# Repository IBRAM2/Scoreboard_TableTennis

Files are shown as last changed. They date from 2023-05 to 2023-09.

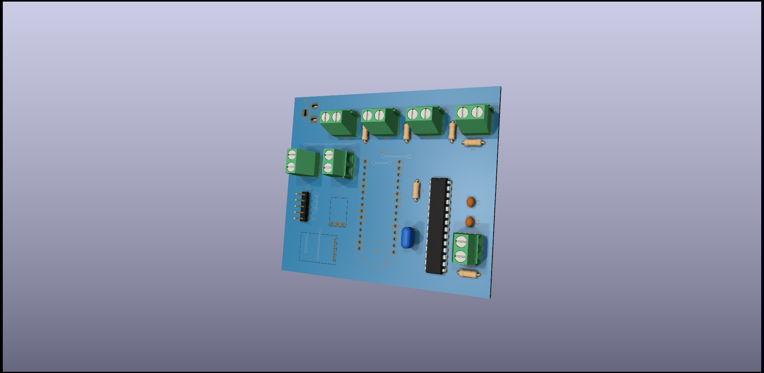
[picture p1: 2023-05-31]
Kicad/MarcadorPing2/MarcadorPing2.png

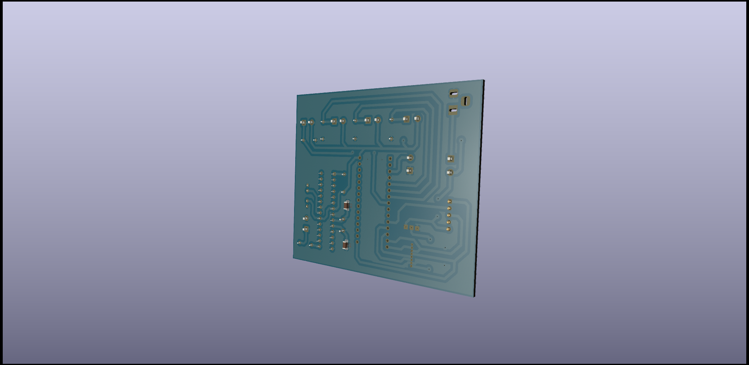
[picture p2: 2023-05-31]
Kicad/MarcadorPing2/MarcadorPing2_2.png

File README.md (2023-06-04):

# Tennis Scoreboard

## Simulation
The software used to perform the circuit simulations is proteus, this software its not free, so I provide a "student" version below.

Download Link: [Proteus Student Version](https://drive.google.com/drive/folders/1Nruetk5m6KCmWx57GLWE98xntiZ9FSeq?usp=drive_link)

### Installation Instructions

You need Windows OS to install proteus
1. Install the .exe, the default ***installation_path*** is: 
    > C:\Program Files (x86)\Labcenter Electronics\Proteus 8 Professional

2. On ***installation_path***/DATA/LIBRARY paste the contents of **"librerias-arduino"**

3. (Optional) On ***installation_path*** remplace Translations directory with the content of **"Paquete de idiomas"**.

### Run Simulation
1. Open **Arduino IDE**, go to File, preferences, and select verbose on compilation.

2. Compile the program, Towards the end of the terminal output, you will be able to see the path where the program was compiled
    > C:\\Users\\name\\AppData\\Local\\Temp\\arduino-sketch-38788937E004AF96E05C05CDE8CDFB3A\Scoreboard.ino.elf
    >
    Copy the path from the terminal or locate the indicated path, remember that the separators are \ and remove the " at the beginning and end.

3. Open the simulation, and double click on arduino nano, paste the path of the file .elf or .hex on **Program File:**

4. Run the simulatior by clicking on the play symbol in the bottom left corner.

*Note: Due to Arduino compiling the program into temporary files, it's possible that program execution may modify the path. However, this usually doesn't happen within the same session unless you restart the computer.*

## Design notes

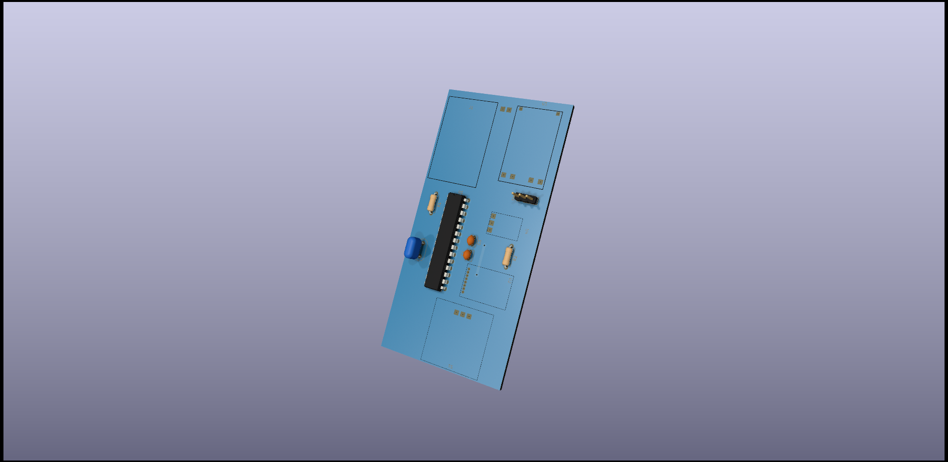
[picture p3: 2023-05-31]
Kicad/MarcadorPing/MarcadorPing.png

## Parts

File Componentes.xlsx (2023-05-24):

Opción 1
Componente | Cantidad | Precio Unitario | Subtotal
MAX7219 Letrero Electrónico Matriz 8x8 (https://uelectronics.com/producto/letrero-electronico-matriz-modulo-8x8-max7219/) | 2 | $122.00 | $244.00
Matriz 8x8 Max7219 Led (https://uelectronics.com/producto/matriz-8x8-max7219-led/) | 2 | $41.00 | $82.00
Interruptor ON OFF Negro 2 Pines 125V 6A (https://uelectronics.com/producto/interruptor-on-off-negro-2-pines-127v-10a/) | 1 | $6.00 | $6.00
Interruptor ON OFF Rojo 2 Pines 125V 6A (https://uelectronics.com/producto/interruptor-on-off-rojo-2-pines-125v-6a/) | 1 | $6.00 | $6.00
PBS-11B Interruptores Push Button Diferentes Colores - Rojo (https://uelectronics.com/producto/pbs-11b-interruptores-push-button-diferentes-colores/?attribute_color=Rojo) | 1 | $11.00 | $11.00
PBS-11B Interruptores Push Button Diferentes Colores - Negro (https://uelectronics.com/producto/pbs-11b-interruptores-push-button-diferentes-colores/?attribute_color=Negro) | 1 | $10.00 | $10.00
PBS-11B Interruptores Push Button Diferentes Colores - Verde (https://uelectronics.com/producto/pbs-11b-interruptores-push-button-diferentes-colores/?attribute_color=Verde) | 1 | $11.00 | $11.00
UNO R3 Con Cable ATMEGA328P / SMD CH340G Compatibles con Arduino - UNO R3 SMD CH340G (https://uelectronics.com/producto/arduino-uno-r3-smd/?attribute_placa=UNO+R3+SMD+CH340G) | 1 | $94.00 | $94.00
 |  | Total | $464.00
Pro Mini 5V 16MHz / 3.3 V 8MHz Compatible con Arduino - 3.3V a 8MHz (https://uelectronics.com/producto/pro-mini-5v-3v3-compatible-con-arduino/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) | 2 | $125.00 | $250.00
Boton Tactil sensor capacitivo TTP223B (https://uelectronics.com/producto/boton-tactil-capacitivo-ttp223b/) | 2 | $14.00 | $28.00
Batería LiPo 3.7V 250mAh 502030 (https://uelectronics.com/producto/bateria-lipo-3-7v-250mah-502030/) | 2 | $39.00 | $78.00
TP4056 con Protección Dual MicroUSB / Tipo C Cargador de Baterías Li-Ion Li-Po - Tipo C (https://uelectronics.com/producto/tp4056-con-proteccion-dual-microusb-tipo-c-cargador-de-baterias-li-ion-li-po/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) | 2 | $15.00 | $30.00
Regulador AMS1117 5V a 3.3V (https://uelectronics.com/producto/regulador-ams1117-5v-a-3-3v/) | 2 | $11.00 | $22.00
NRF24L01 Transreceptor SMD con Antena 2.4Ghz (https://uelectronics.com/producto/nrf24l01-transreceptor-smd-con-antena-2-4ghz/) | 3 | $31.00 | $93.00
Interruptor 1 Polo 2 Tiros 3p 2.54mm Pitch (https://uelectronics.com/producto/interruptor-1-polo-2-tiros-3p-2-54mm-pitch/) | 4 | $2.00 | $8.00
 |  | Total | $509.00
 |  | Total Final | $973.00
Opción 2
Componente | Cantidad | Precio Unitario | Subtotal
MAX7219 Letrero Electrónico Matriz 8x8 (https://uelectronics.com/producto/letrero-electronico-matriz-modulo-8x8-max7219/) | 2 | $122.00 | $244.00
Matriz 8x8 Max7219 Led (https://uelectronics.com/producto/matriz-8x8-max7219-led/) | 2 | $41.00 | $82.00
Interruptor ON OFF Negro 2 Pines 125V 6A (https://uelectronics.com/producto/interruptor-on-off-negro-2-pines-127v-10a/) | 1 | $6.00 | $6.00
Interruptor ON OFF Rojo 2 Pines 125V 6A (https://uelectronics.com/producto/interruptor-on-off-rojo-2-pines-125v-6a/) | 1 | $6.00 | $6.00
PBS-11B Interruptores Push Button Diferentes Colores - Rojo (https://uelectronics.com/producto/pbs-11b-interruptores-push-button-diferentes-colores/?attribute_color=Rojo) | 1 | $11.00 | $11.00
PBS-11B Interruptores Push Button Diferentes Colores - Negro (https://uelectronics.com/producto/pbs-11b-interruptores-push-button-diferentes-colores/?attribute_color=Negro) | 1 | $10.00 | $10.00
PBS-11B Interruptores Push Button Diferentes Colores - Verde (https://uelectronics.com/producto/pbs-11b-interruptores-push-button-diferentes-colores/?attribute_color=Verde) | 1 | $11.00 | $11.00
Nano Tipo C / Micro USB Compatible con Arduino - Tipo C (https://uelectronics.com/producto/arduino-uno-r3-smd/?attribute_placa=UNO+R3+SMD+CH340G) | 1 | $118.00 | $118.00
Header Macho Tira de 40 Pines 2.54mm (https://uelectronics.com/producto/header-macho-tira-de-40-pines-2-54mm/) | 2 | $4.00 | $8.00
Cables Dupont Largos 20cm HH MH MM - Hembra-Hembra (https://uelectronics.com/producto/cables-dupont-largos-20cm-hh-mh-mm/?attribute_pa_terminal=hembra-hembra) | 1 | $22.00 | $22.00
 |  | Total | $518.00
Oscilador Cristal Cuarzo HC-49S - 8 Mhz (https://uelectronics.com/producto/oscilador-cristal-cuarzo-hc-49s/?attribute_pa_cristal-cuarzo=8-mhz) | 2 | $4.00 | $8.00
Boton Tactil sensor capacitivo TTP223B (https://uelectronics.com/producto/boton-tactil-capacitivo-ttp223b/) | 2 | $14.00 | $28.00
Batería LiPo 3.7V 250mAh 502030 (https://uelectronics.com/producto/bateria-lipo-3-7v-250mah-502030/) | 2 | $39.00 | $78.00
TP4056 con Protección Dual MicroUSB / Tipo C Cargador de Baterías Li-Ion Li-Po - Tipo C (https://uelectronics.com/producto/tp4056-con-proteccion-dual-microusb-tipo-c-cargador-de-baterias-li-ion-li-po/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) | 2 | $15.00 | $30.00
Regulador AMS1117 5V a 3.3V (https://uelectronics.com/producto/regulador-ams1117-5v-a-3-3v/) | 2 | $11.00 | $22.00
NRF24L01 Transreceptor SMD con Antena 2.4Ghz (https://uelectronics.com/producto/nrf24l01-transreceptor-smd-con-antena-2-4ghz/) | 3 | $31.00 | $93.00
Interruptor 1 Polo 2 Tiros 3p 2.54mm Pitch (https://uelectronics.com/producto/interruptor-1-polo-2-tiros-3p-2-54mm-pitch/) | 4 | $2.00 | $8.00
Base Socket 16 Pines IC DIP-16 Slim (https://uelectronics.com/producto/base-socket-16-pines-ic-dip-16-slim/) | 4 | $4.00 | $16.00
Capacitor Cerámico 1206 22pF 50V TCC1206COG220J500DT (https://uelectronics.com/producto/capacitor-ceramico-1206-22pf-50v-tcc1206cog220j500dt/) | 4 | $1.00 | $4.00
Capacitor 100nF 0.1uF 104 (https://uelectronics.com/producto/capacitor-ceramico-100nf-0-1uf-104/) | 6 | $1.00 | $6.00
Matriz Resistor 4.7K Ohms 1206 (https://uelectronics.com/producto/matriz-resistor-4-7k-ohms-1206/) | 4 | $2.00 | $8.00
Resistencias de precisión 1/4 W Valores de 100 a 10k. - 10k (https://uelectronics.com/producto/resistencia-1-4w-presicion/?attribute_pa_resistencia=10k) | 2 | $0.40 | $0.80
Conector Dc Power Jack Socket Hembra para Arduino (https://uelectronics.com/producto/conector-dc-power-jack-socket-hembra-para-arduino/) | 1 | $3.00 | $3.00
Fuente de Alimentacion 5V 2A / 9V 1A / 12V 1A - 5V 2A (https://uelectronics.com/producto/fuente-de-alimentacion-5v-2a-9v-1a-12v-1a/?attribute_voltaje=5V+2A) | 1 | $61.00 | $61.00
 |  | Total | $365.80
 |  | Total Final | $883.80
Los que lean esto son bien novatos en el ping pong

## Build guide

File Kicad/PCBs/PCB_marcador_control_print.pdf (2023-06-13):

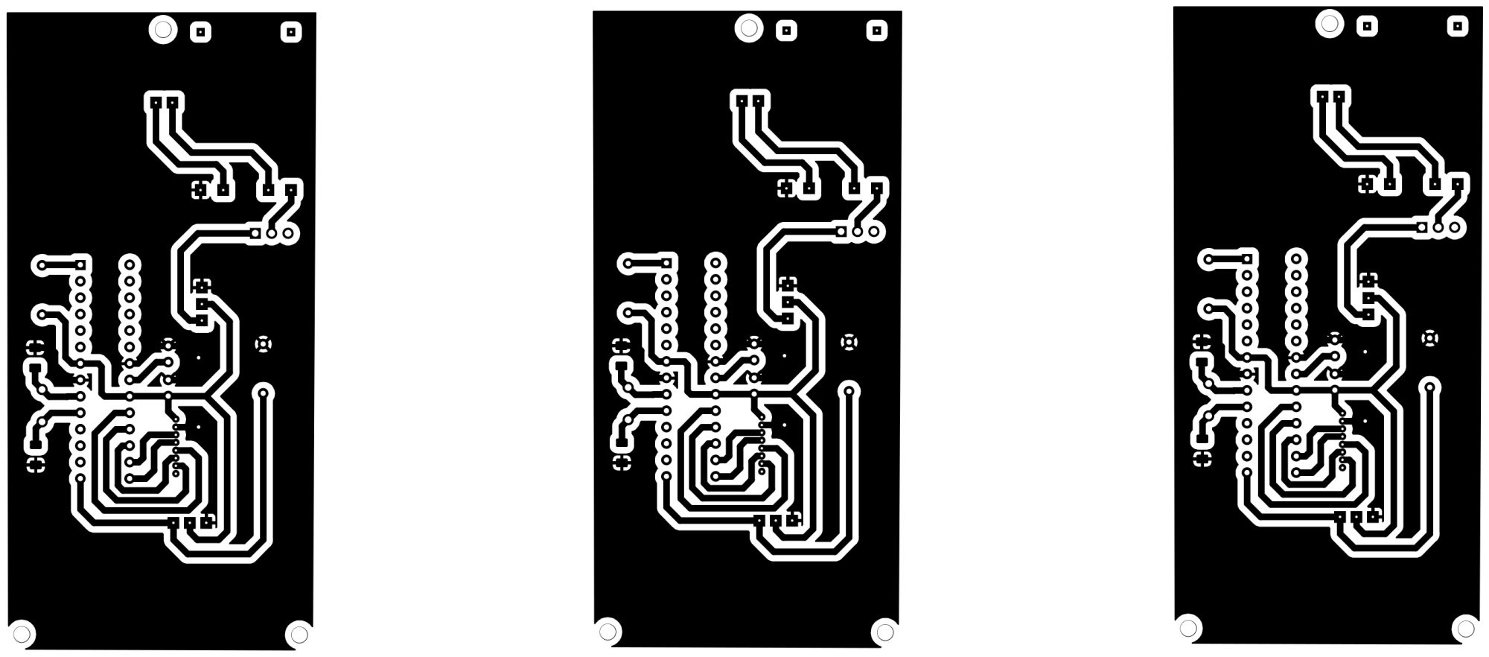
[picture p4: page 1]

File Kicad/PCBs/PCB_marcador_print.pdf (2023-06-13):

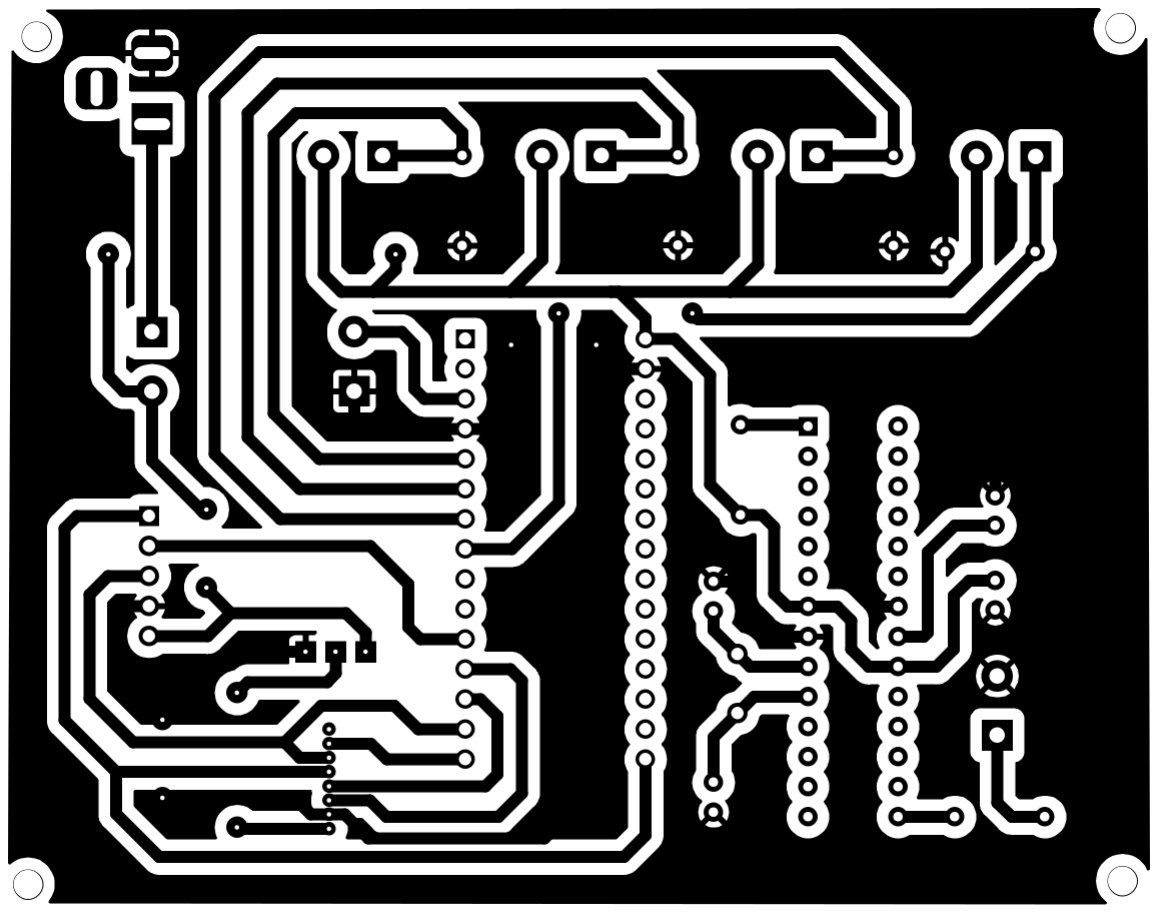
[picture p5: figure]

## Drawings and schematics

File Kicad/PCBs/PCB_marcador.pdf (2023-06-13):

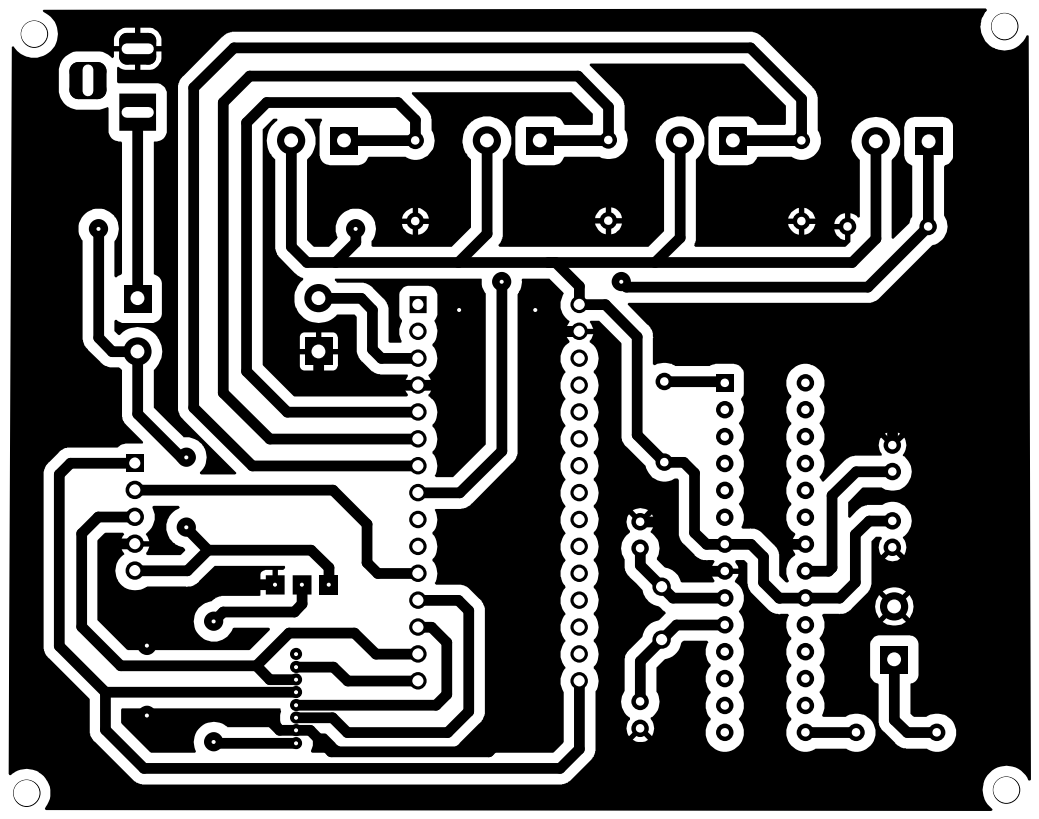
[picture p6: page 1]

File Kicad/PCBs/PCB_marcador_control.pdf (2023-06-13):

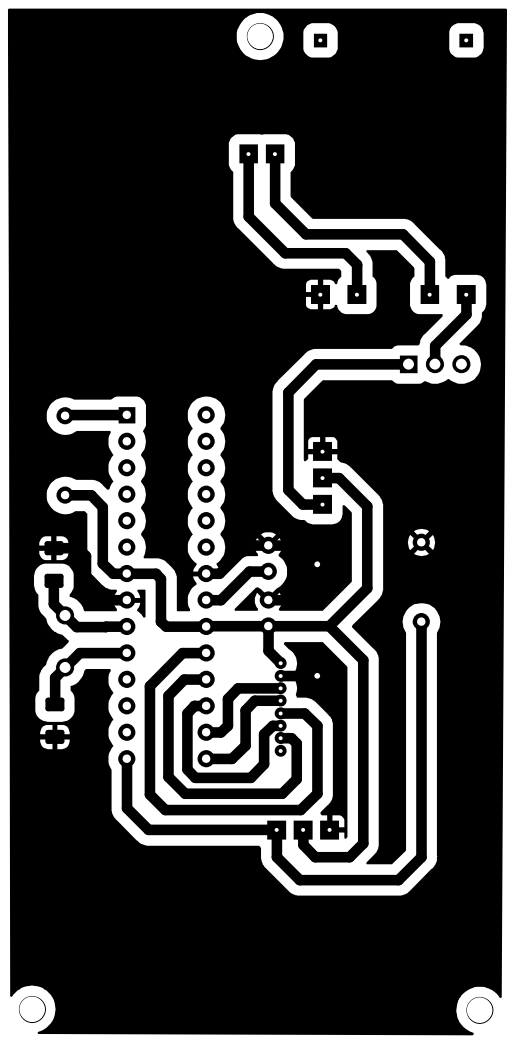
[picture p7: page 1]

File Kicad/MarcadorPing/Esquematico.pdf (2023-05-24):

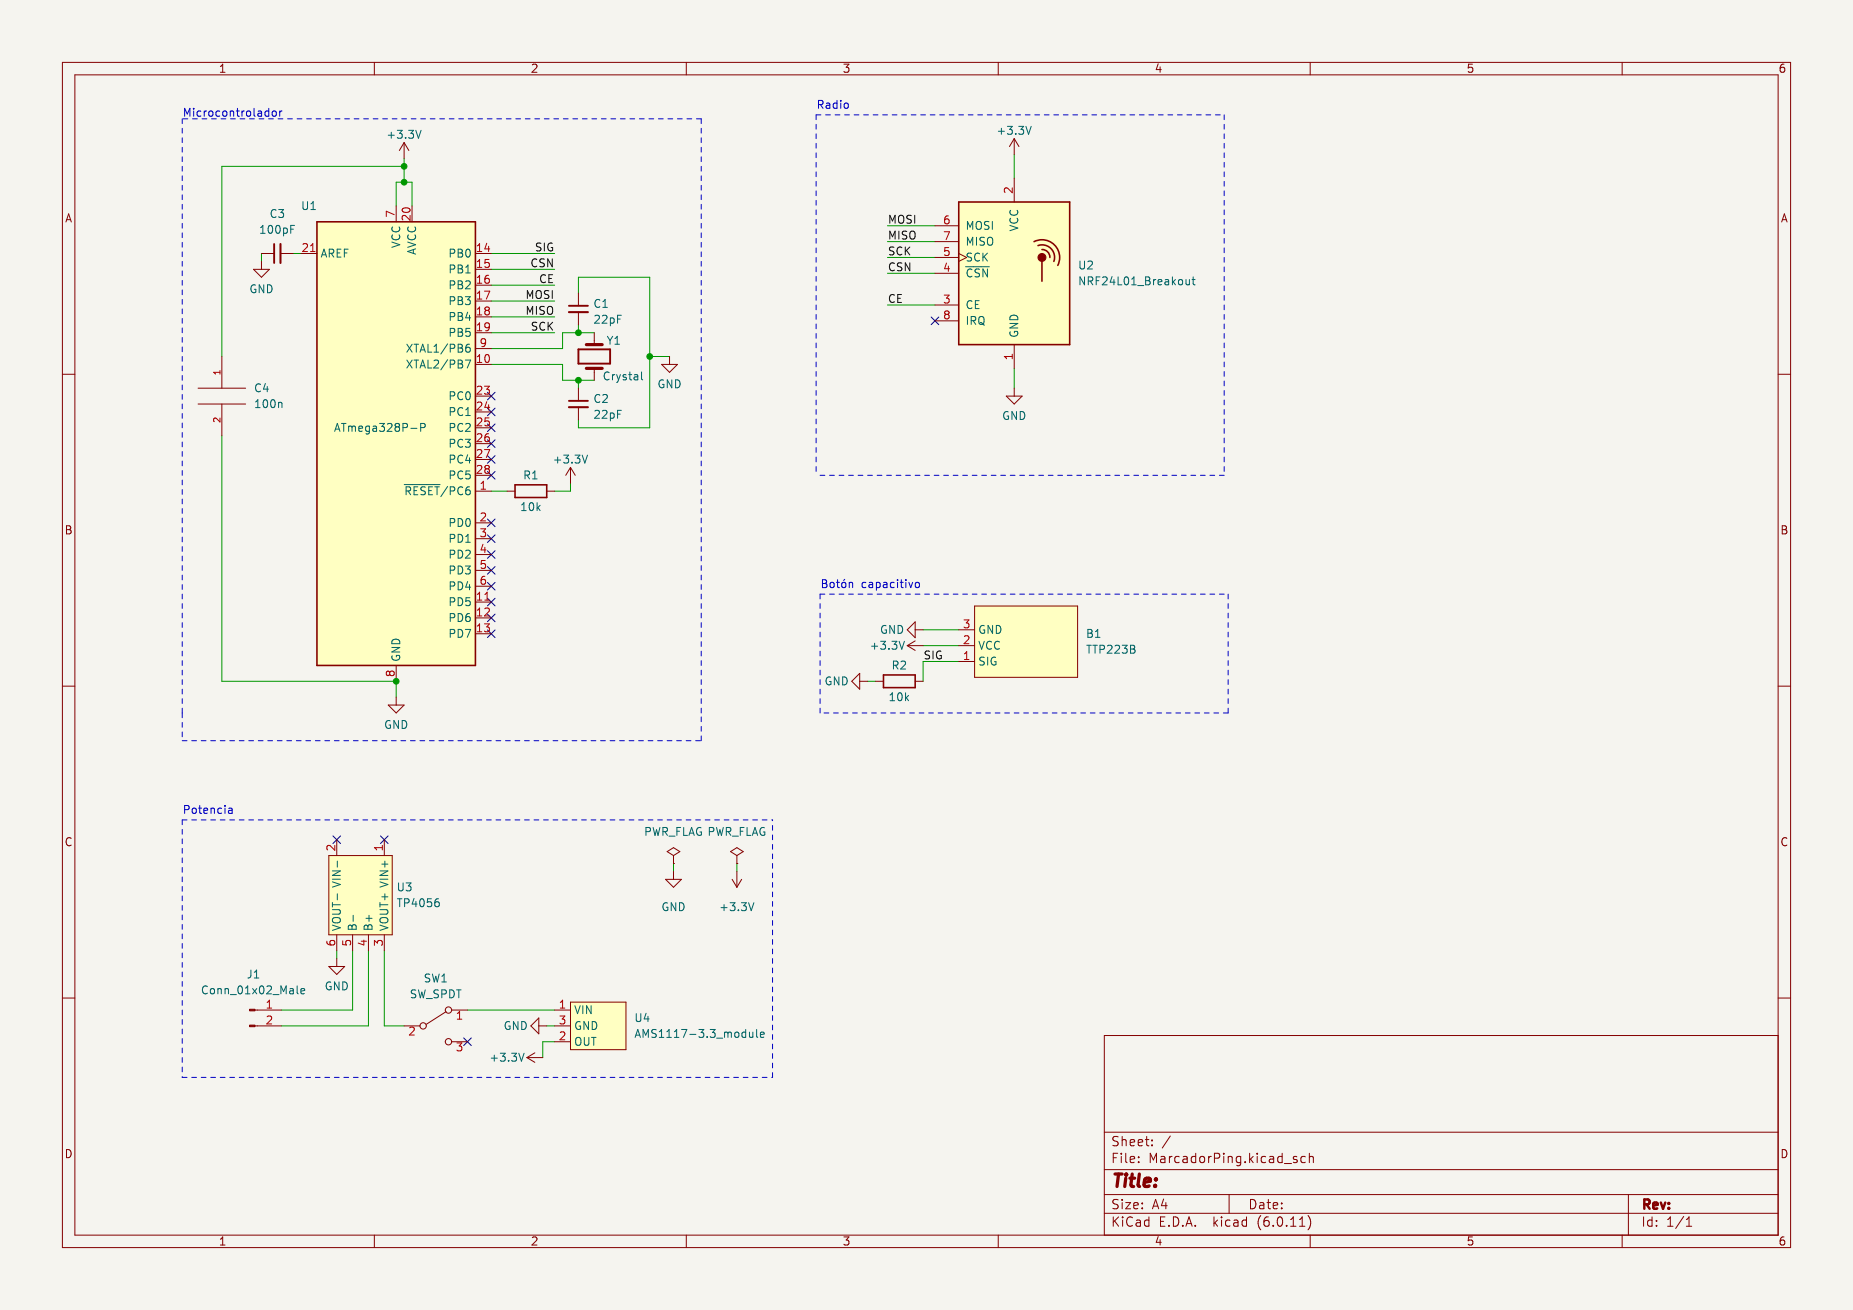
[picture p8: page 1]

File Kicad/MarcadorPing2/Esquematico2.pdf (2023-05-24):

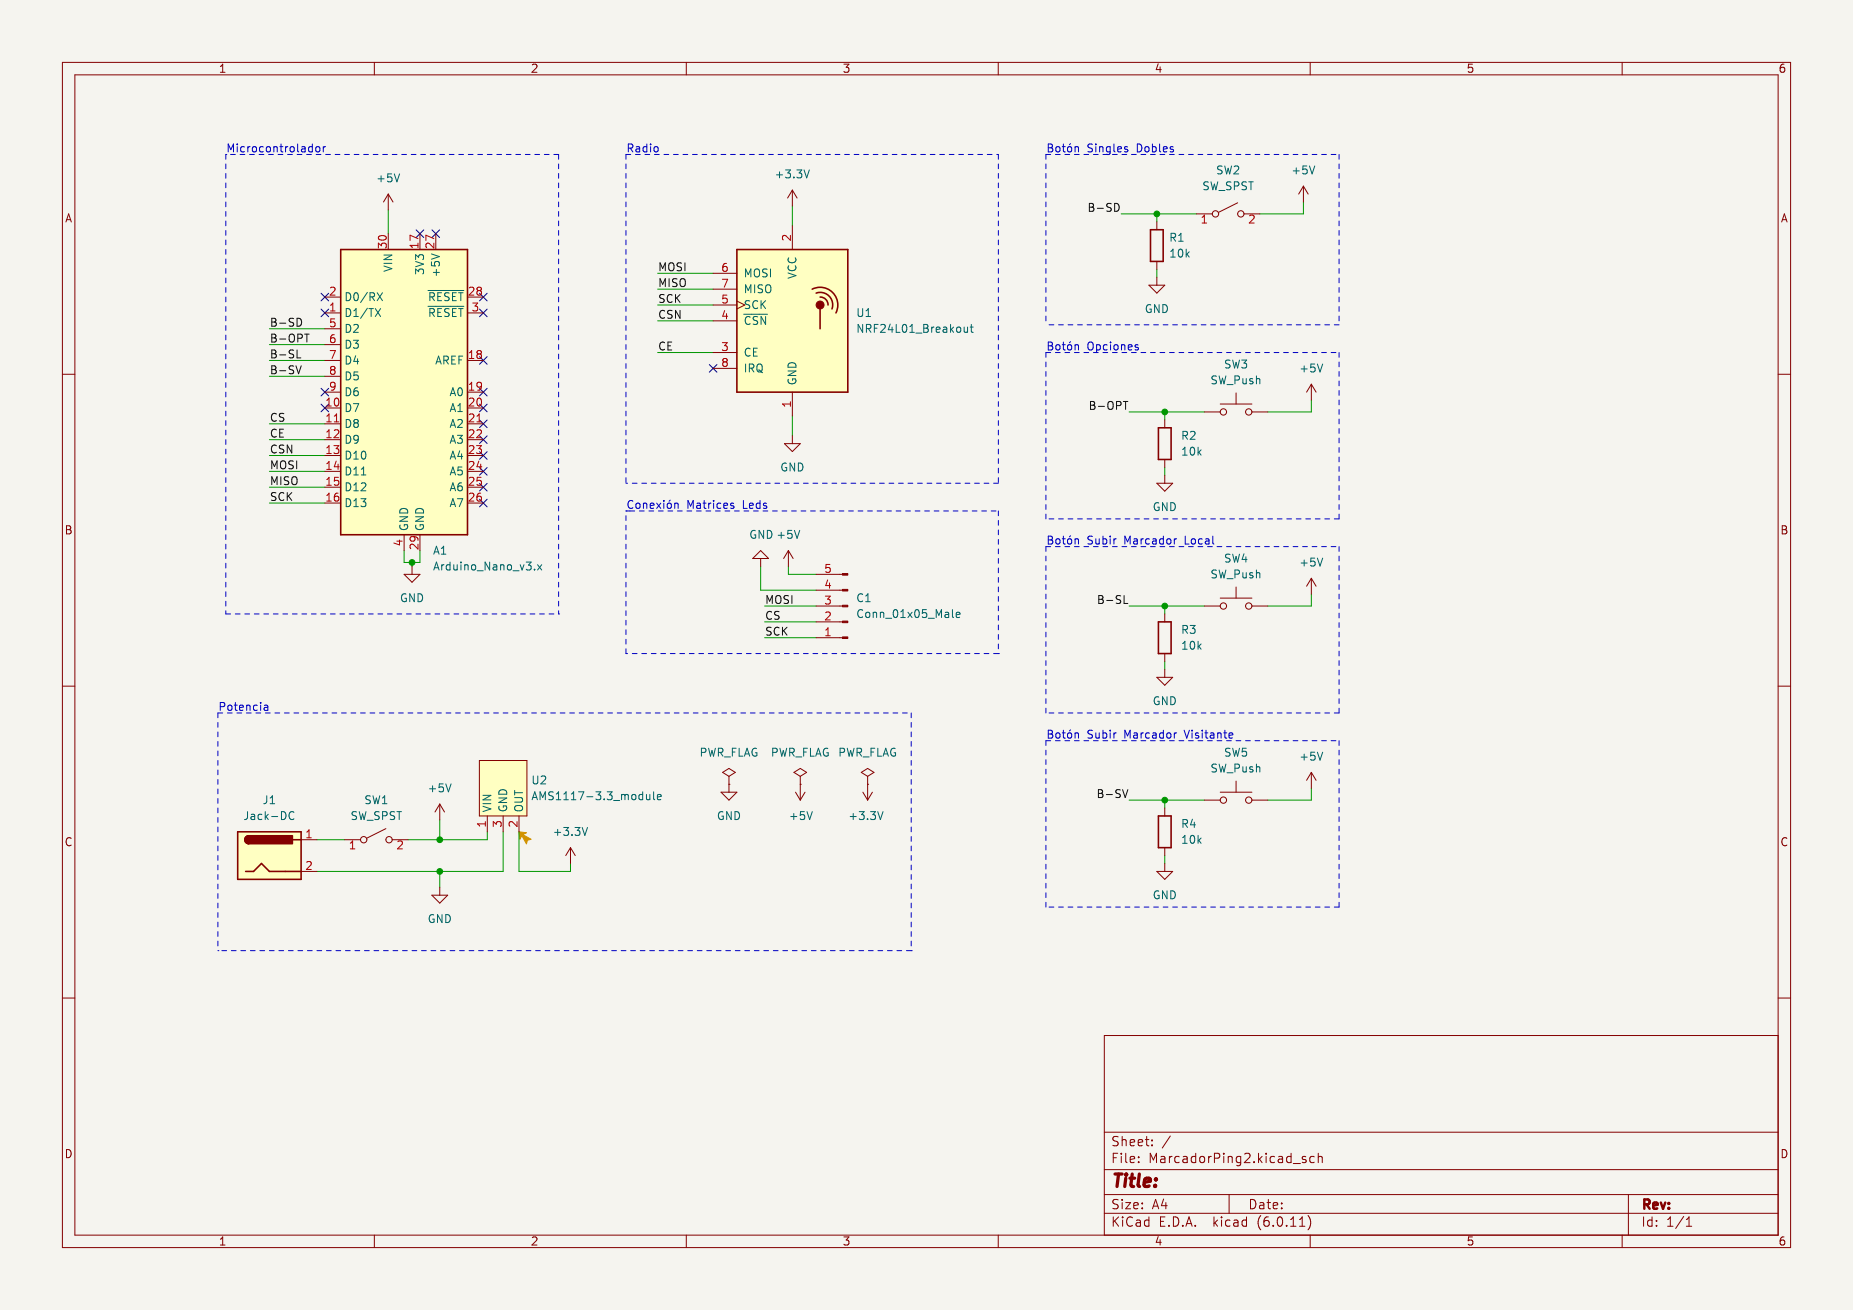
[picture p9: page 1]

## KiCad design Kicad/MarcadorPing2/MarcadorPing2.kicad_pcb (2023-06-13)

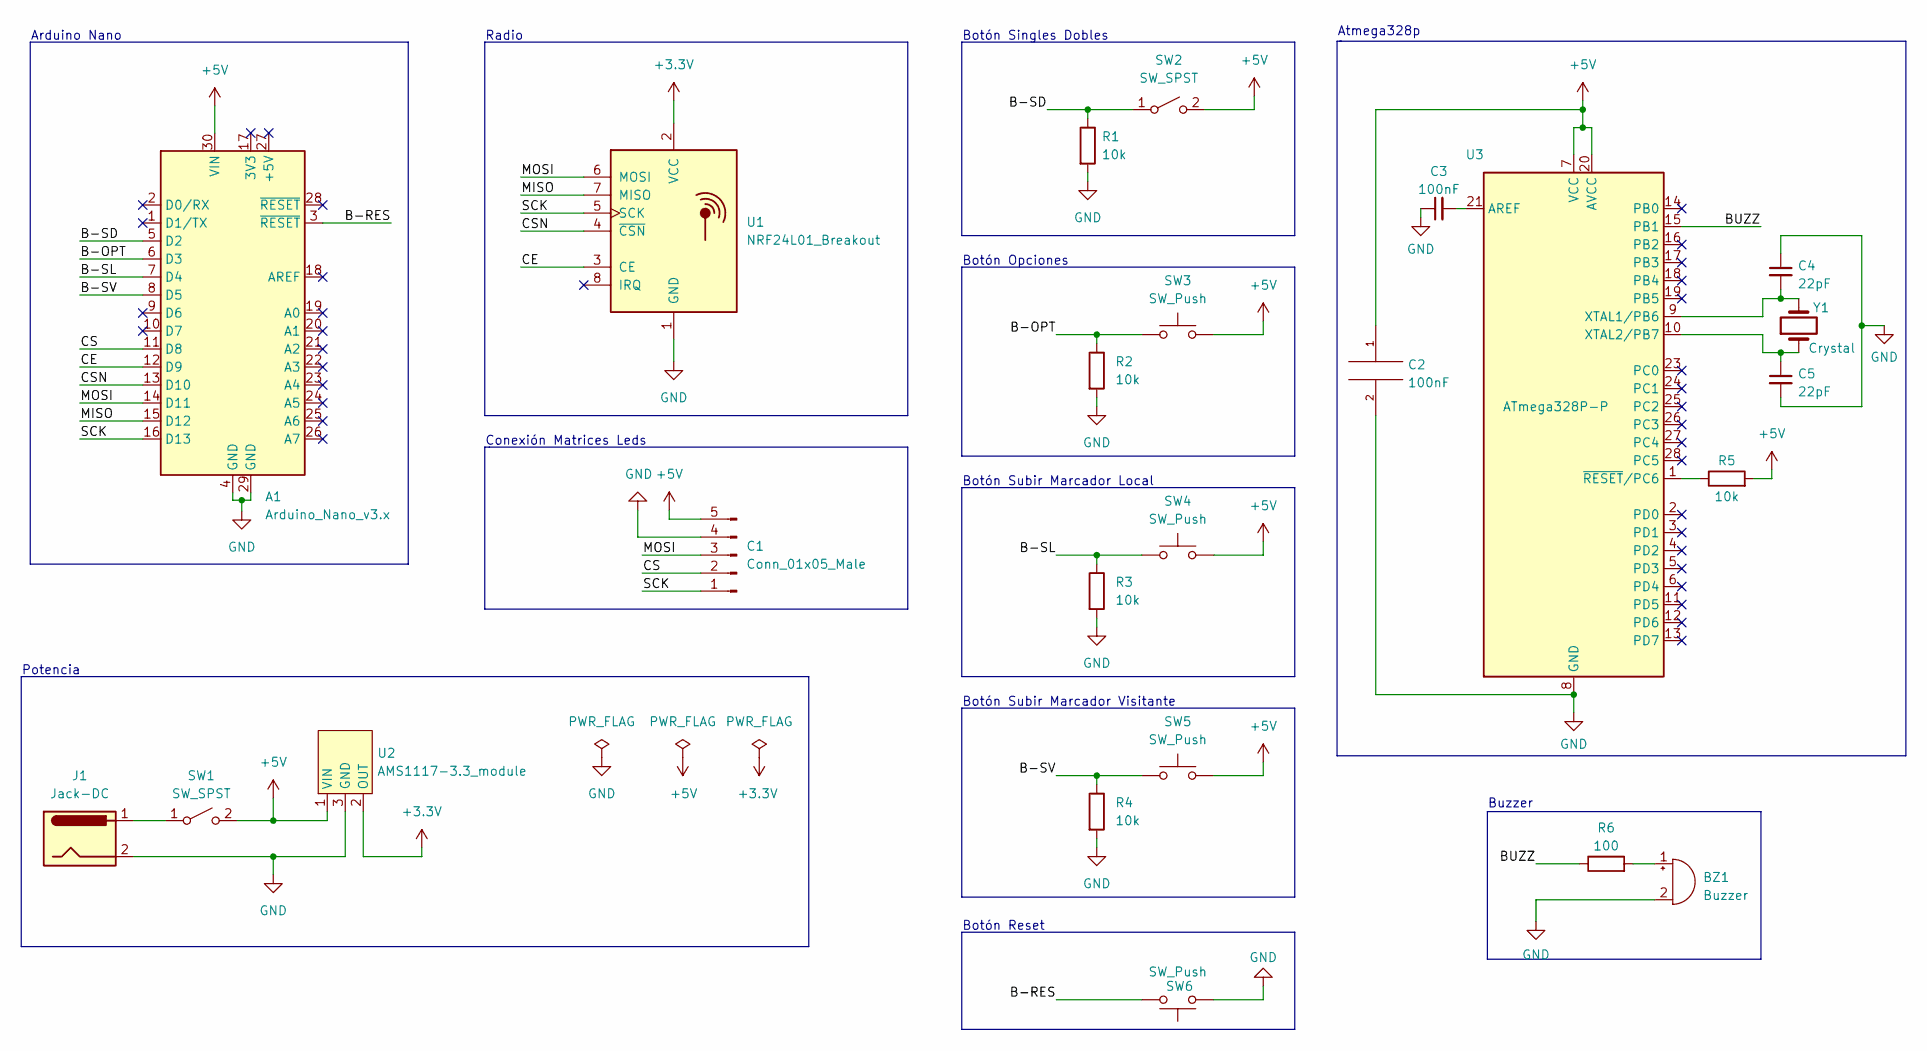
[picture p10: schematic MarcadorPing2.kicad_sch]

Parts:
A1: Arduino_Nano_v3.x; Arduino_Nano
BZ1: Buzzer; TerminalBlock_Phoenix_MKDS-1,5-2_1x02_P5.00mm_Horizontal
C1: Conn_01x05_Male; PinHeader_1x05_P2.54mm_Vertical
C2, C3: 100nF; C_Disc_D3.8mm_W2.6mm_P2.50mm
C4, C5: 22pF; C_1206_3216Metric_Pad1.33x1.80mm_HandSolder
J1: Jack-DC; BarrelJack_Horizontal
R1, R2, R3, R4, R5: 10k; R_Axial_DIN0207_L6.3mm_D2.5mm_P7.62mm_Horizontal
R6: 100; R_Axial_DIN0207_L6.3mm_D2.5mm_P7.62mm_Horizontal
SW1, SW2: SW_SPST; TerminalBlock_Phoenix_MKDS-1,5-2_1x02_P5.00mm_Horizontal
SW3, SW4, SW5, SW6: SW_Push; TerminalBlock_Phoenix_MKDS-1,5-2_1x02_P5.00mm_Horizontal
U1: NRF24L01_Breakout; NRF24L01
U2: AMS1117-3.3_module; AMS1117
U3: ATmega328P-P; DIP-28_W7.62mm
Y1: Crystal; Resonator-2Pin_W8.0mm_H3.5mm

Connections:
+3.3V: U1.2 (VCC), U2.2 (OUT)
+5V: A1.30 (VIN), C1.5, C2.1, R5.2, SW1.2 (B), SW2.2 (B), SW3.2, SW4.2, SW5.2, U2.1 (VIN), U3.7 (VCC), U3.20 (AVCC)
/B-OPT: A1.6 (D3), R2.1, SW3.1
/B-RES: A1.3 (~RESET), SW6.2
/B-SD: A1.5 (D2), R1.1, SW2.1 (A)
/B-SL: A1.7 (D4), R3.1, SW4.1
/B-SV: A1.8 (D5), R4.1, SW5.1
/BUZZ: R6.1, U3.15 (PB1)
/CE: A1.12 (D9), U1.3 (CE)
/CS: A1.11 (D8), C1.2
/CSN: A1.13 (D10), U1.4 (~CSN)
/MISO: A1.15 (D12), U1.7 (MISO)
/MOSI: A1.14 (D11), C1.3, U1.6 (MOSI)
/SCK: A1.16 (D13), C1.1, U1.5 (SCK)
GND: A1.4 (GND), A1.29 (GND), BZ1.2 (+), C1.4, C2.2, C3.1, C4.1, C5.2, J1.2, R1.2, R2.2, R3.2, R4.2, SW6.1, U1.1 (GND), U2.3 (GND), U3.8 (GND), U3.22 (GND)
unnamed: BZ1.1 (-), R6.2
unnamed: J1.1, SW1.1 (A)
unnamed: C3.2, U3.21 (AREF)
unnamed: C4.2, U3.9 (XTAL1/PB6), Y1.2
unnamed: C5.1, U3.10 (XTAL2/PB7), Y1.1
unnamed: R5.1, U3.1 (~RESET/PC6)

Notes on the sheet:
Radio
Conexión Matrices Leds
Buzzer
Botón Subir Marcador Local
Botón Opciones
Botón Subir Marcador Visitante
Atmega328p
Potencia
Arduino Nano
Botón Reset
Botón Singles Dobles

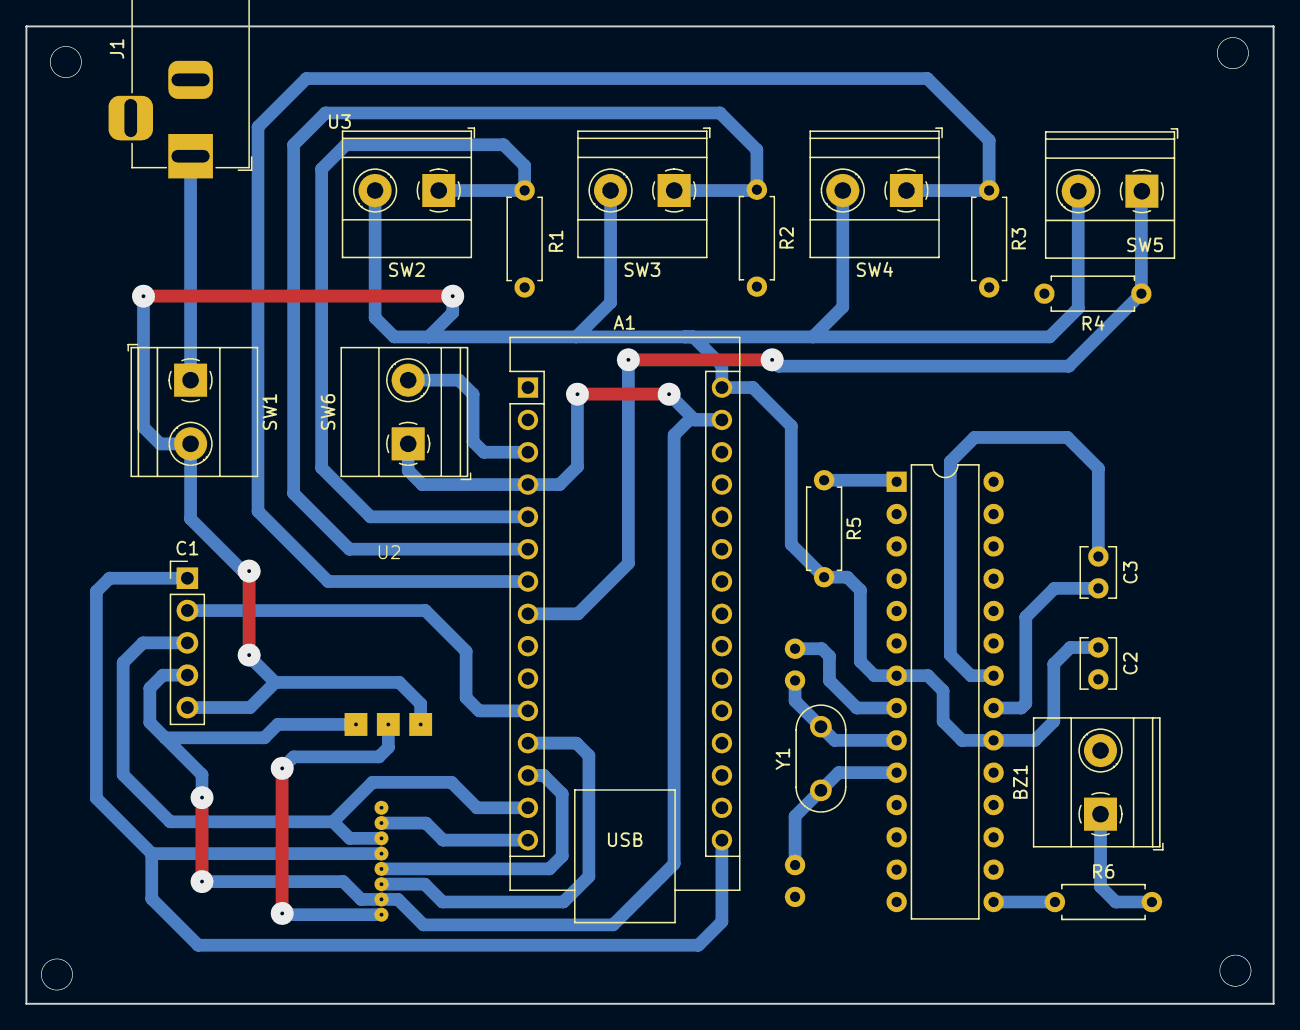
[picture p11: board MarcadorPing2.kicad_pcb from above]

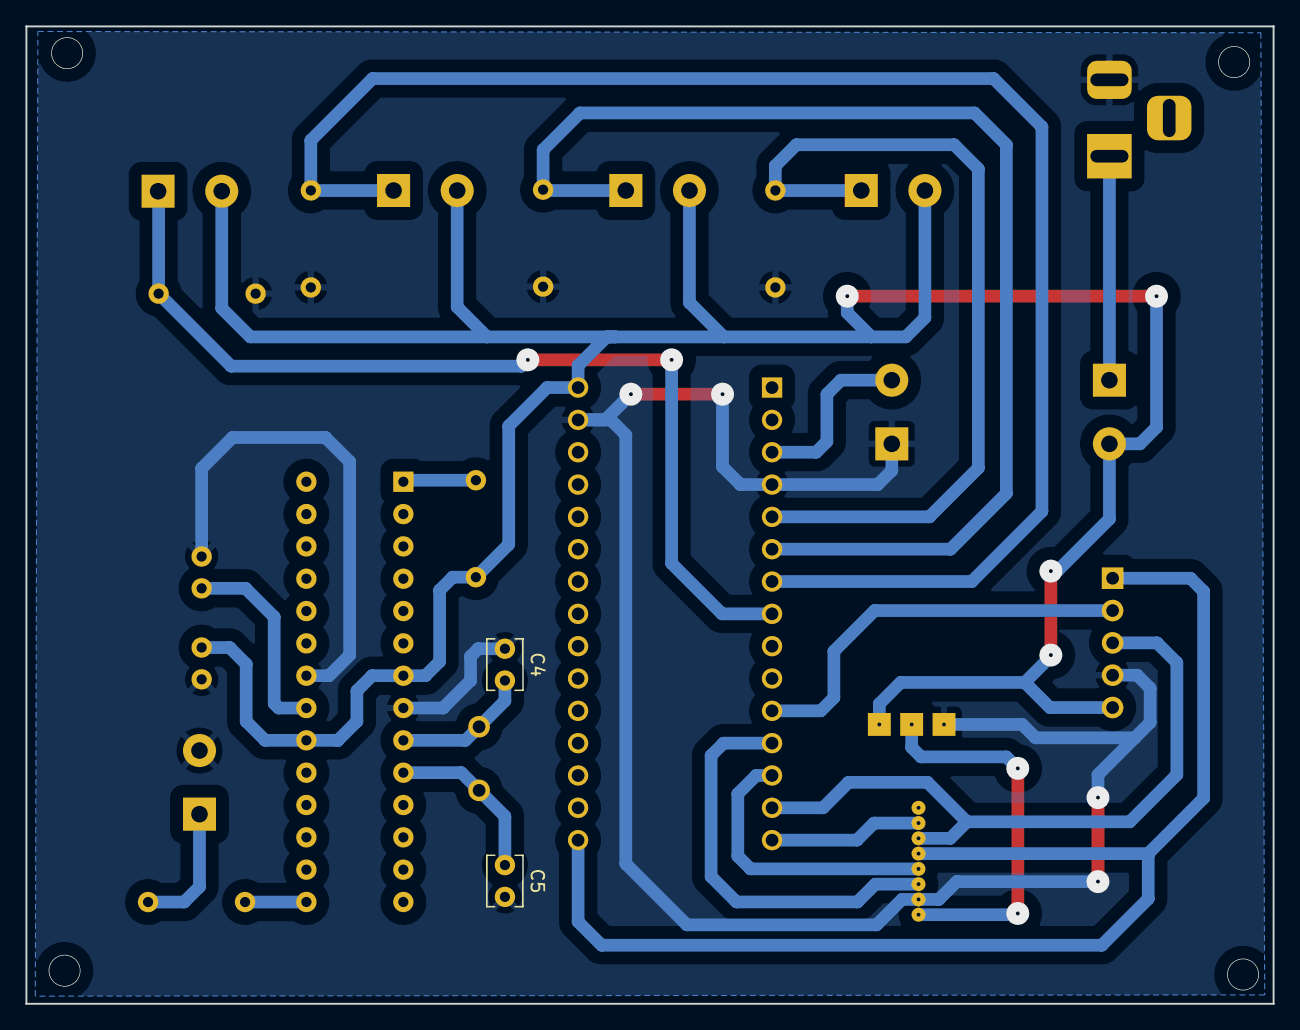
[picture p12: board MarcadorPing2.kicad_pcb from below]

Board: 2 copper layers, 98.0 x 76.8 mm, 24 parts (2 on the bottom side), 21 nets.

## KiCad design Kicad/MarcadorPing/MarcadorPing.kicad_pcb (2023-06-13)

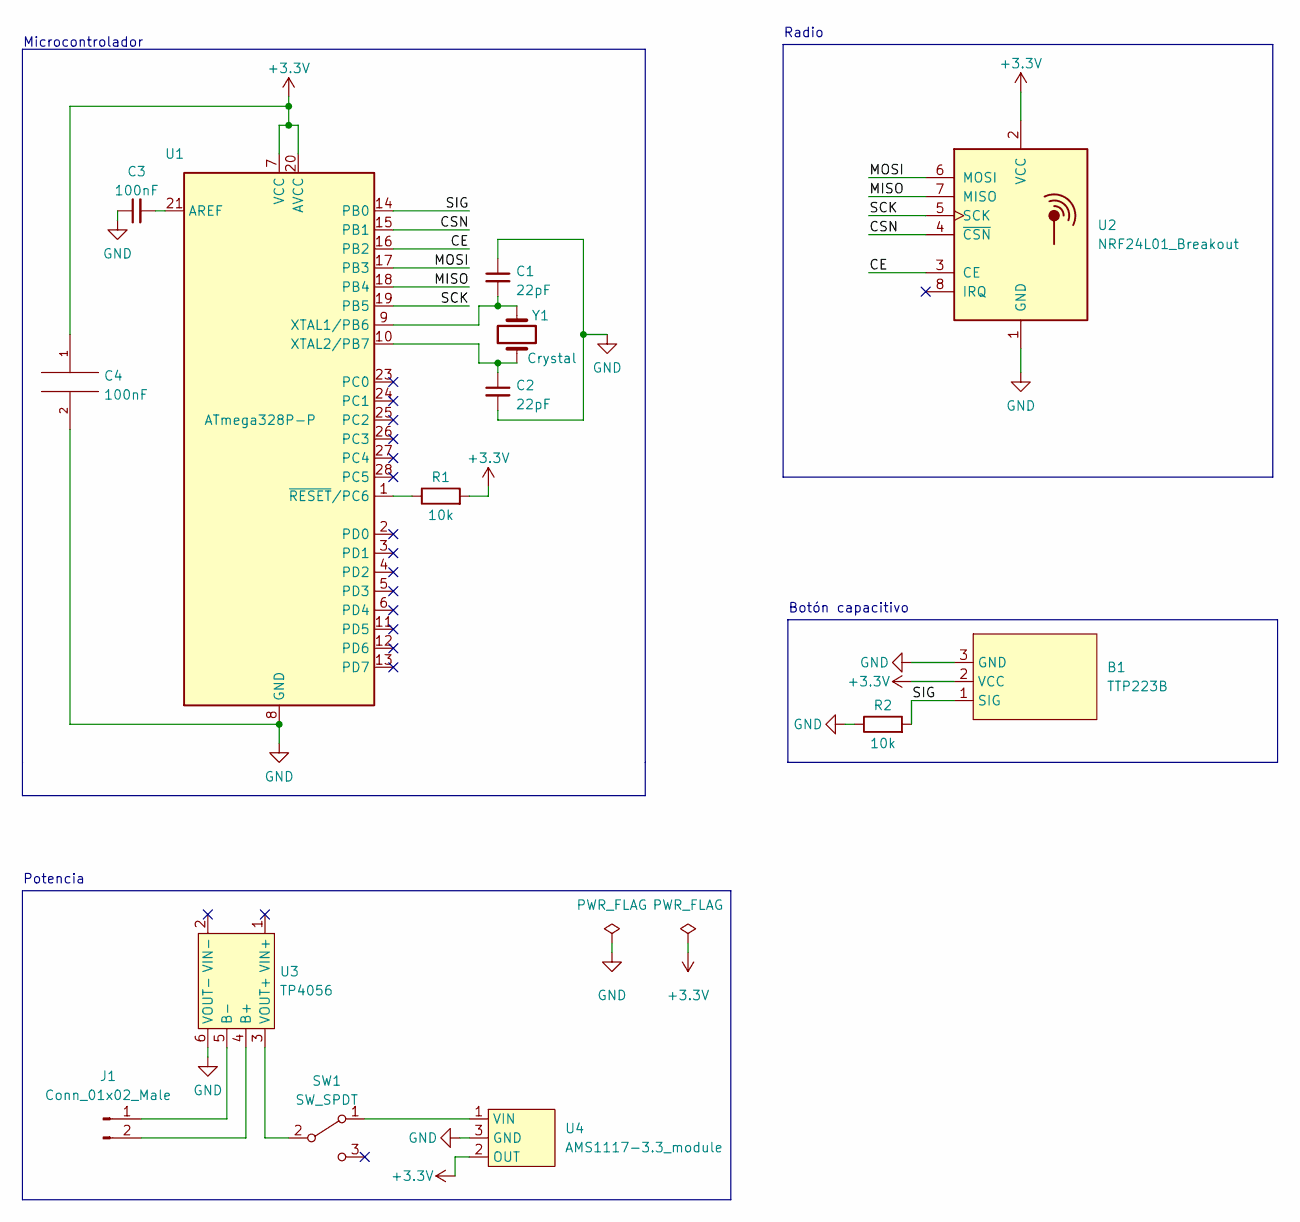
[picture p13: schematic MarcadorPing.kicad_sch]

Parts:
B1: TTP223B
C1, C2: 22pF; C_1206_3216Metric_Pad1.33x1.80mm_HandSolder
C3, C4: 100nF; C_Disc_D3.8mm_W2.6mm_P2.50mm
J1: Conn_01x02_Male; LiPo 502030
R1, R2: 10k; R_Axial_DIN0207_L6.3mm_D2.5mm_P7.62mm_Horizontal
SW1: SW_SPDT; PinHeader_1x03_P2.54mm_Vertical
U1: ATmega328P-P; DIP-28_W7.62mm
U2: NRF24L01_Breakout; NRF24L01
U3: TP4056
U4: AMS1117-3.3_module; AMS1117
Y1: Crystal; Resonator-2Pin_W8.0mm_H3.5mm

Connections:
+3.3V: B1.2 (VCC), C4.1, R1.2, U1.7 (VCC), U1.20 (AVCC), U2.2 (VCC), U4.2 (OUT)
/CE: U1.16 (PB2), U2.3 (CE)
/CSN: U1.15 (PB1), U2.4 (~CSN)
/MISO: U1.18 (PB4), U2.7 (MISO)
/MOSI: U1.17 (PB3), U2.6 (MOSI)
/SCK: U1.19 (PB5), U2.5 (SCK)
/SIG: B1.1 (SIG), R2.2, U1.14 (PB0)
GND: B1.3 (GND), C1.1, C2.2, C3.1, C4.2, R2.1, U1.8 (GND), U1.22 (GND), U2.1 (GND), U3.6 (VOUT-), U4.3 (GND)
unnamed: J1.1, U3.5 (B-)
unnamed: J1.2, U3.4 (B+)
unnamed: SW1.1 (A), U4.1 (VIN)
unnamed: SW1.2 (B), U3.3 (VOUT+)
unnamed: C3.2, U1.21 (AREF)
unnamed: C1.2, U1.9 (XTAL1/PB6), Y1.2
unnamed: C2.1, U1.10 (XTAL2/PB7), Y1.1
unnamed: R1.1, U1.1 (~RESET/PC6)

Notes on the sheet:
Radio
Botón capacitivo
Microcontrolador
Potencia

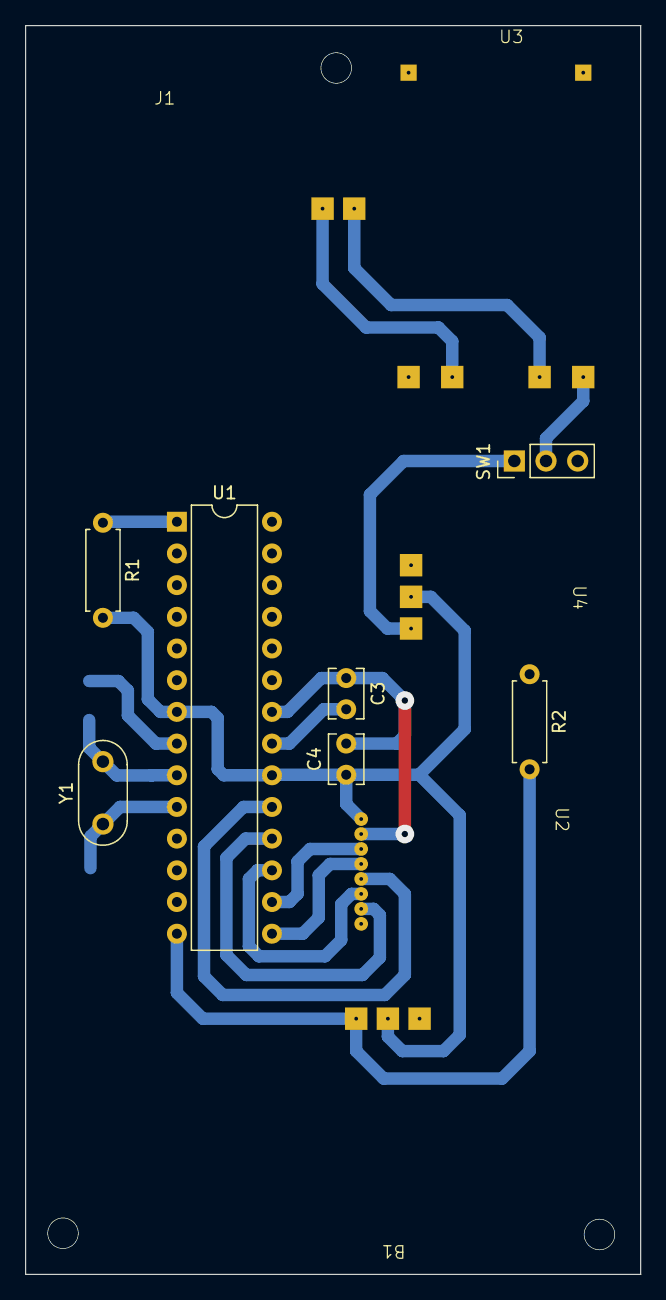
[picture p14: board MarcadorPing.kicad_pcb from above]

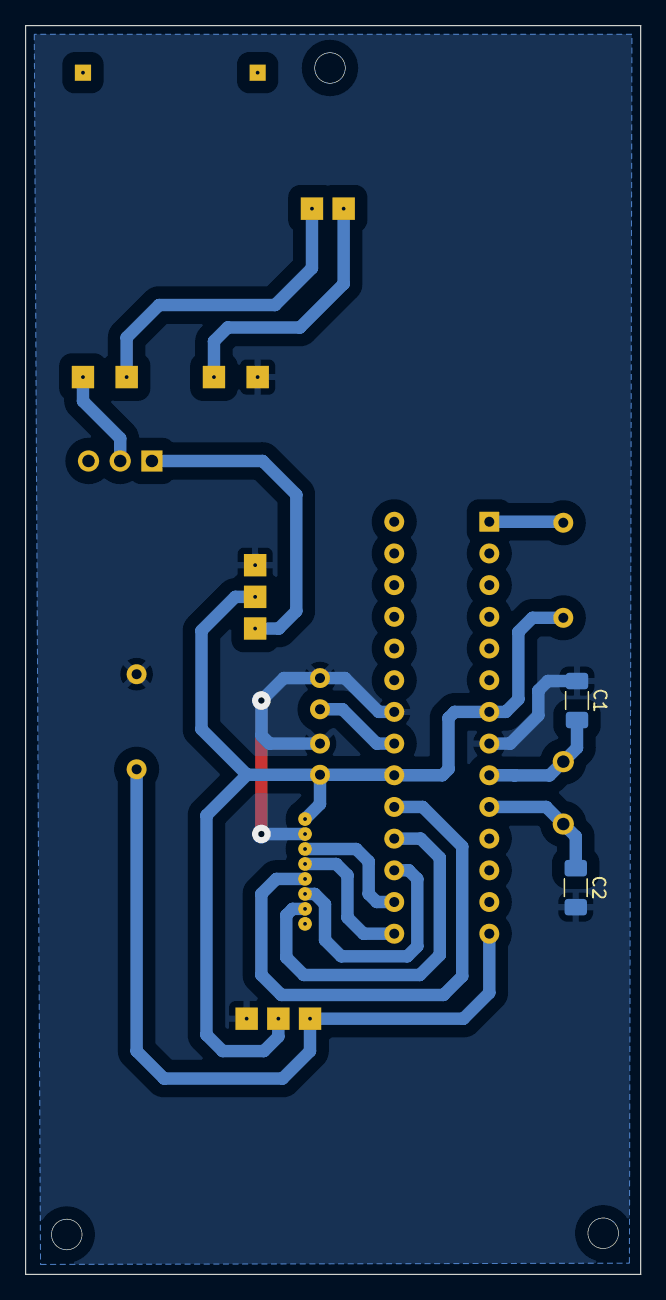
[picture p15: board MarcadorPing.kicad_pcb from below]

Board: 2 copper layers, 49.3 x 100.1 mm, 14 parts (2 on the bottom side), 16 nets.

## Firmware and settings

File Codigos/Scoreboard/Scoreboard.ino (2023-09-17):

//*********Marcador Ping pong Profesional****************
//Creditos:
//Iván Ibrahim Fernández Morales
//Luis Roberto Villa Salas
//Hector Varela Santos

#include <MD_MAX72xx.h>
#include <SPI.h>
#include "numeros.h"  // Librería pa dibujar los numeros en la matriz

//Define pines SPI
#define MOSI 11
#define SCK 13
#define SS 8
#define BUZZ_ACT 7
//Numero de matrices
#define NUM_MAT 10

//Instancia objeto
MD_MAX72XX mxObj = MD_MAX72XX(MD_MAX72XX::GENERIC_HW, SS, NUM_MAT);

//Mapea matrices a utilizar
int colMat_1[2][2] = {{5,1},{4,0}};
int colMat_2[2][2] = {{7,3},{6,2}};
int colMat_3[2] = {8,9};

//Mapeo de servicios
uint8_t S_Singles[4] = {1,2,1,2};
uint8_t S_Doubles1[4] = {1,4,3,2};
uint8_t S_Doubles2[4] = {2,3,4,1};
uint8_t S_Doubles3[4] = {3,2,1,4};
uint8_t S_Doubles4[4] = {4,1,2,3};
uint8_t Serve[4];

//Mapeo de botones
uint8_t B_SD = 2;
uint8_t B_OPT = 3;
uint8_t B_SL = 4;
uint8_t B_SV = 5;

//Inicializa contadores
uint8_t contL = 0;
uint8_t contV = 0;
uint8_t contSetL = 0;
uint8_t contSetV = 0;
uint8_t contS = 0;
uint8_t cont_pos = 0;
uint8_t suma = 0;

//Variable de cambio de servicio
bool Doubles;

//Inicializa variables de singles o dobles
//Doubles = 0;

//Setup
//*****************************************************************************
void setup() {
  //Inicializa objeto
  mxObj.begin();

  //Inicializa pines de entrada (Botones)
  //Botón de opciones
  pinMode(B_OPT, INPUT);
  //Botón marcador local
  pinMode(B_SL, INPUT);
  //Botón marcador visitante
  pinMode(B_SV, INPUT);
  
  //Pin de activación de victoria (Buzzer)
  pinMode(BUZZ_ACT, OUTPUT);
  digitalWrite(BUZZ_ACT, LOW);

  //Lee entrada digital de selección de sobles o singles
  Doubles = digitalRead(B_SD);

  //Define si es singles o dobles
  if(Doubles)
    for(uint8_t i = 0; i < 4; i++)
      Serve[i] = S_Doubles1[i];
  else
    for(uint8_t i = 0; i < 4; i++)
      Serve[i] = S_Singles[i];

  //Inciliza numeros en el marcador
  Numero(contL, colMat_1, mxObj);
  Numero(contV, colMat_2, mxObj);
  //Inicializa Sacador
  Servicio(Serve[contS], mxObj);
  //Inicializa Sets
  Sets(contSetL, colMat_3, 0, mxObj);
  Sets(contSetV, colMat_3, 1, mxObj);
}

//Ciclo plrincipal
//*****************************************************************************
void loop() 
{

  //Cambia posición de sacardor si el partido aún no empieza
  if(contL+contV == 0 && digitalRead(B_OPT))
    {
    cambiaServicio(Serve, &contS);
    delay(500);
    }

  //Punto de jugador local
  if(digitalRead(B_SL))
  { 
    subeLocal(&contL);
    suma = contL+contV;
    asignaServicio(Serve, &contS, suma);
    if(contL >= 11 && contL-2 >= contV)
    {
      Victoria(1, &contL, &contV, &contS, Serve);
      subeSet(&contSetL, 0);
    }
    delay(500);
  }

  //Punto de jugador visitante
  if(digitalRead(B_SV))
  {
    subeVisita(&contV);
    suma = contL+contV;
    asignaServicio(Serve, &contS, suma);
    if(contV >= 11 && contV-2 >= contL)
    {
      Victoria(2, &contL, &contV, &contS, Serve);
      subeSet(&contSetV, 1);
    }
    delay(500);
  }
}

//Funciones
//*****************************************************************************

//Función para subir marcador de jugador local
//---------------------------------------------------------------
void subeLocal(uint8_t *contL)
{
  *contL = *contL+1;
  Numero(*contL, colMat_1, mxObj);
}

//Función para subir marcador de jugador visitante
//---------------------------------------------------------------
void subeVisita(uint8_t *contV)
{
  *contV = *contV+1;
  Numero(*contV, colMat_2, mxObj);
}

//Función para subir set
//---------------------------------------------------------------
void subeSet(uint8_t *cont, uint8_t player)
{
  *cont = *cont+1;
  Sets(*cont, colMat_3, player, mxObj);
}

//Función para conocer sacador
//---------------------------------------------------------------
void asignaServicio(uint8_t Serve[4], uint8_t *contS, uint8_t suma)
{
  if(suma <=20)
  {
    if(suma%2 == 0)
    {
      LimpiaServ(Serve[*contS], mxObj);
      *contS = *contS+1;
      if(*contS > 3)
        *contS = 0;
      Servicio(Serve[*contS], mxObj);
    }
    else
      Servicio(Serve[*contS], mxObj);
  }
  else
  {
    LimpiaServ(Serve[*contS], mxObj);
    *contS = *contS+1;
    if(*contS > 3)
      *contS = 0;
    Servicio(Serve[*contS], mxObj);
  }
}
//Función de victoria
//---------------------------------------------------------------
void Victoria(uint8_t team, uint8_t *contL, uint8_t *contV, uint8_t *contS, uint8_t Serve[4])
{
  digitalWrite(BUZZ_ACT, HIGH);
  delay(300);
  digitalWrite(BUZZ_ACT, LOW);
  delay(5000);
  *contL = 0;
  *contV = 0;
  *contS = 0;
  Numero(*contL, colMat_1, mxObj);
  Numero(*contV, colMat_2, mxObj);
  Servicio(Serve[*contS], mxObj);
}

//Función de cambio de sacador manual
//---------------------------------------------------------------
void cambiaServicio(uint8_t Serve[4], uint8_t *contS)
{ 
  LimpiaServ(Serve[*contS], mxObj);
  
  if(Doubles)
  {
    cont_pos = cont_pos+1;
    if(cont_pos > 3)
      cont_pos = 0;
    cambiaMapeo(cont_pos);
    *contS = 0;
    Servicio(Serve[*contS], mxObj);
  }
  else
  {
    *contS = *contS+1;
    if(*contS > 3)
      *contS = 0;
    Servicio(Serve[*contS], mxObj);
  }
}

//Función de cambio de mapeo de dobles
//---------------------------------------------------------------
void cambiaMapeo(uint8_t cambio)
{
  switch(cambio)
  {
    case 0:
      for(uint8_t i = 0; i < 4; i++)
        Serve[i] = S_Doubles1[i];
    break;

    case 1:
      for(uint8_t i = 0; i < 4; i++)
        Serve[i] = S_Doubles2[i];
    break;

    case 2:
      for(uint8_t i = 0; i < 4; i++)
        Serve[i] = S_Doubles3[i];
    break;

    case 3:
      for(uint8_t i = 0; i < 4; i++)
        Serve[i] = S_Doubles4[i];
    break;
  }
}

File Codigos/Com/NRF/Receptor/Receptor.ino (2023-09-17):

#include <SPI.h>
#include <RF24.h>

RF24 radio(10,9);

// const byte identificacion[6] = "00001";

void setup()
{
  //inicializamos el puerto serie
  Serial.begin(9600); 

  //inicializamos el NRF24L01 
  radio.begin();
  radio.setChannel(0x55);
  //Abrimos el canal de Lectura
  radio.openReadingPipe(0, 0xF0F0F0F0AA);
  radio.setAutoAck(false);
  // Nivel de transmisión
  radio.setPALevel(RF24_PA_MIN);
  //Datarate
  // radio.setDataRate(RF24_250KBPS);
  // empezamos a escuchar por el canal
  radio.startListening();
  radio.powerUp(); //Power up the radio
}

void loop() {
 if (radio.available() )
 {   
    char text[32] = "default";
     //Leemos los datos y los guardamos en la variable datos[]
     radio.read(&text,sizeof(text));
     Serial.println(text);
 }
 else
 {
     Serial.println("No hay datos de radio disponibles");
 }
 delay(1000);
}

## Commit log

2023-05-24 LiPo 502030 library updated
2023-05-31 diseño pcb
    [MarcadorPing.kicad_pcb, MarcadorPing.kicad_sch, MarcadorPing2.kicad_pcb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]
2023-06-01 Mapeo de los numeros para los Sets
2023-06-04 Implementacion de sets
2023-06-13 Cambios placas
    [MarcadorPing.kicad_pcb, MarcadorPing2.kicad_pcb, MarcadorPing2.kicad_sch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]
